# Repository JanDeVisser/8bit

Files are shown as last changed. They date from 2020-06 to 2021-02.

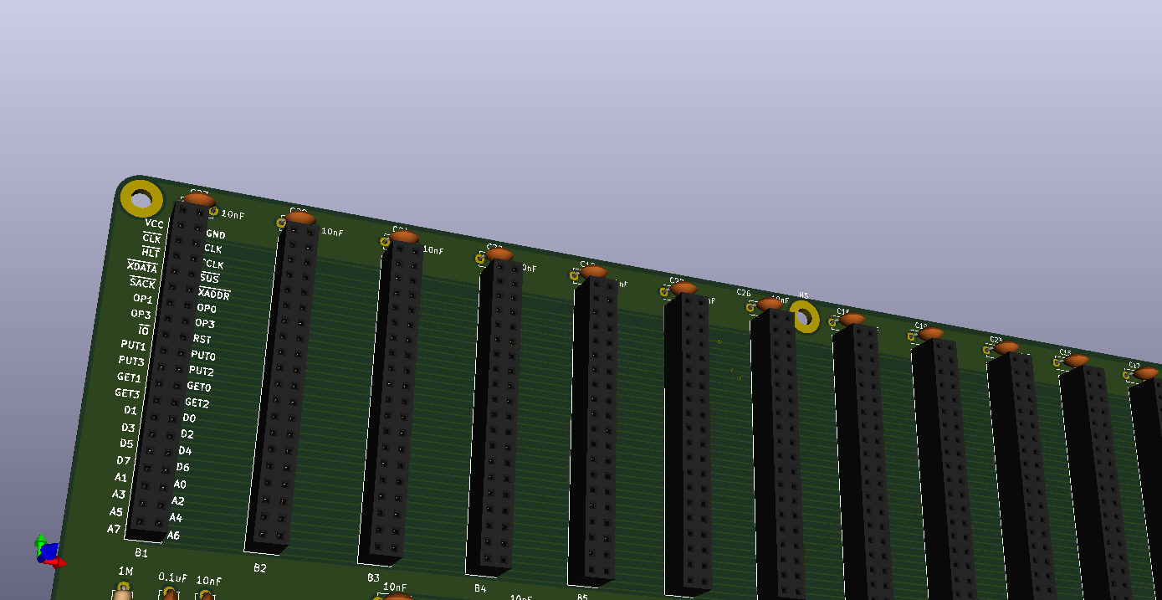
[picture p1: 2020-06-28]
backplane/bus-labels.png

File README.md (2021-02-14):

# A Simple Ben Eater Inspired 8-bit computer

Please describe me.

### Register IDs

ID       | Register       |  R W  | Remarks
---------|----------------|-------|--------------
0000 00  | A              |  x x  |
0001 01  | B              |  x x  |
0010 02  | C              |  x x  |
0011 03  | D              |  x x  |
0100 04  | ALU LHS/Result |  x x  | Put: LHS, Get: Result
0101 05  | ALU Operation  |  - x  | Put: RHS, OP0-3: Operation
0110 06  | Instruction    |  - x  |
0111 07  | Mem            |  x x  |
1000 08  | Prog Counter   |  x x  |
1001 09  | SP             |  x x  |
1010 10  | Si             |  x x  |
1011 11  | Di             |  x x  |
1100 12  | TX             |       |
1101 13  |                |       |
1110 14	 | Monitor        |  x -  |
1111 15  | Mem Addr       |  - x  |

### Control Lines

Pin   | Name                   | Description
------|------------------------|-----------------------
1     | `GND`                  | Common Ground
2     | `VCC`                  | +5V Power
3     | `CLK`                  | Square Wave Clock
4     | ~~`CLK`~~              | Reverse Clock
5     | `^CLK`                 | "Burst" Clock at rising edge of CLK
6     | `HLT`                  | Halts clock
7     | ~~`SUS`~~              | Requests Control Unit to cease dispatching instructions.
8     | ~~`XDATA`~~            | 8 bit Data transfer instruction
9     | ~~`XADDR`~~            | 16 bit address transfer instruction
10    | ~~`SACK`~~             | Set by Control Unit as acknowlegement of SUS.
11-14 | `OP0`-`OP3`            | Custom Operation codes used by various instructions. See below.
15    | `RST`                  | Reset
16    | ~~`IO`~~               | In/Out instruction
17-20 | `PUT0`-`PUT3`          | Register ID of the target of a transfer instruction.
21-24 | `GET0`-`GET3`          | Register ID of the source of a transfer instruction.
25-32 | `D0`-`D7`              | Databus
33-40 | `A0`-`A7` / `A8`-`A15` | Address bus

### Operation Codes

#### XADDR

OP0-3 |Function
---|---
`XX01`|Increment source (Get) register
`XX10`|Decrement source (Get) register

#### XDATA

_When moving data between 8- and 16-bit registers:_

OP0-3 |Function
------|--------
`XXX0`|Transfer to/from the LSB of the 16-bit register
`XXX1`|Transfer to/from the MSB of the 16-bit register

_When the target register is ALU Operation (`0x5`):_

OP0-3|Operation
-----|-----------
`0x0`|`ADD`
`0x1`|`ADC`
`0x2`|`SUB`
`0x3`|`SBB`
...|...
`0x8`|`AND`
`0x9`|`OR`
`0xA`|`XOR`
`0xB`|`NOT LHS`
`0xC`|`SHL`
`0xD`|`SHR`
`0xE`|`CLR`
...|...

## N O T E S

### SBB (Subtract with Borrow)

See here: https://en.wikipedia.org/wiki/Carry_flag#Vs._borrow_flag

We use the convention that when subtracting the processor Carry flag is a borrow flag. This is in line with the Z80 and x68.

### 74xxx253 Function Table

As determined by Julian Ilett in https://www.youtube.com/watch?v=15M63Zqkthk

C3-C0 :arrow_down: BA :arrow_right: | 11 | 10 | 01 | 00 | Operation
------|----|----|----|----|-----------
  0x0  | 0  | 0  | 0  | 0  | All Zero
  0x1  | 0  | 0  | 0  | 1  | A NOR B
  0x2  | 0  | 0  | 1  | 0  | A AND (NOT B)
  0x3  | 0  | 0  | 1  | 1  | NOT B
  0x4  | 0  | 1  | 0  | 0  | (NOT A) AND B
  0x5  | 0  | 1  | 0  | 1  | NOT A
  0x6  | 0  | 1  | 1  | 0  | A XOR B
  0x7  | 0  | 1  | 1  | 1  | A NAND B
  0x8  | 1  | 0  | 0  | 0  | A AND B
  0x9  | 1  | 0  | 0  | 1  | A XNOR B
  0xA  | 1  | 0  | 1  | 0  | A
  0xB  | 1  | 0  | 1  | 1  | A OR (NOT B)
  0xC  | 1  | 1  | 0  | 0  | B
  0xD  | 1  | 1  | 0  | 1  | (NOT A) OR B
  0xE  | 1  | 1  | 1  | 0  | A OR B
  0xF  | 1  | 1  | 1  | 1  | All One

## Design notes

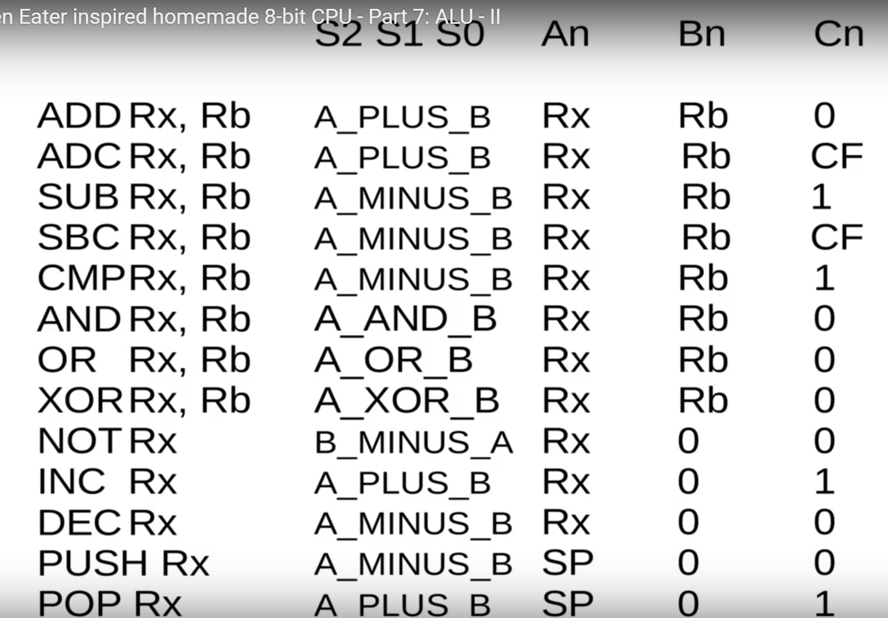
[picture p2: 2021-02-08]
JamesBates_74LS382.png

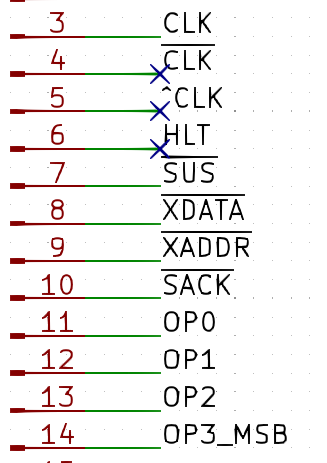
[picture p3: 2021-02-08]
ControlLines.png

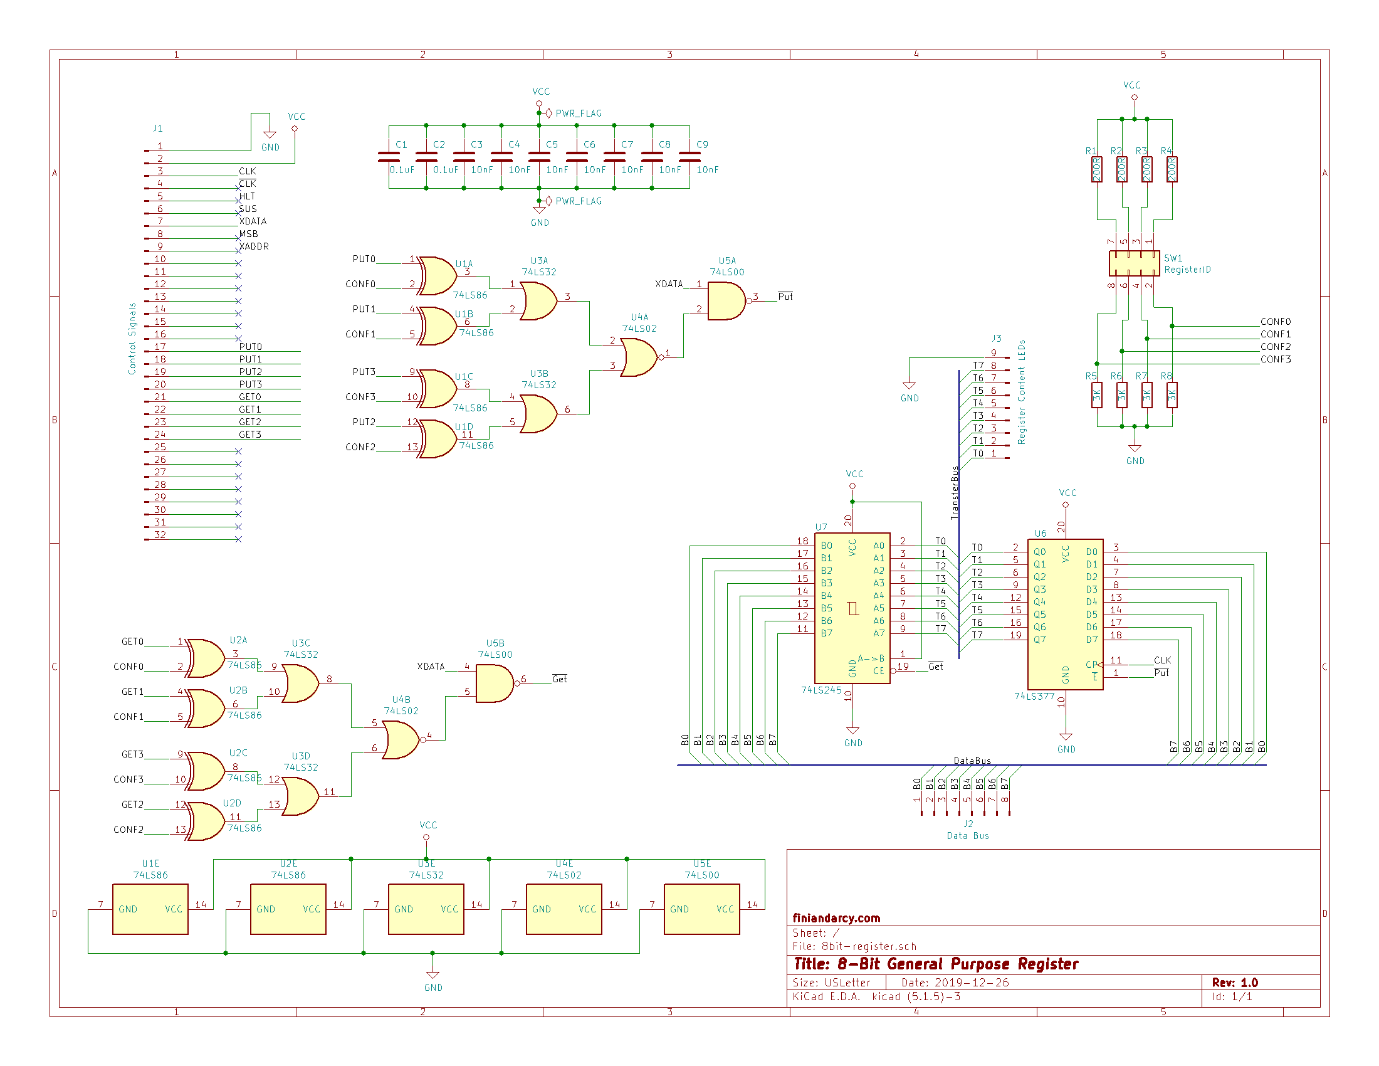
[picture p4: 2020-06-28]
8bit-register/8bit-register.png

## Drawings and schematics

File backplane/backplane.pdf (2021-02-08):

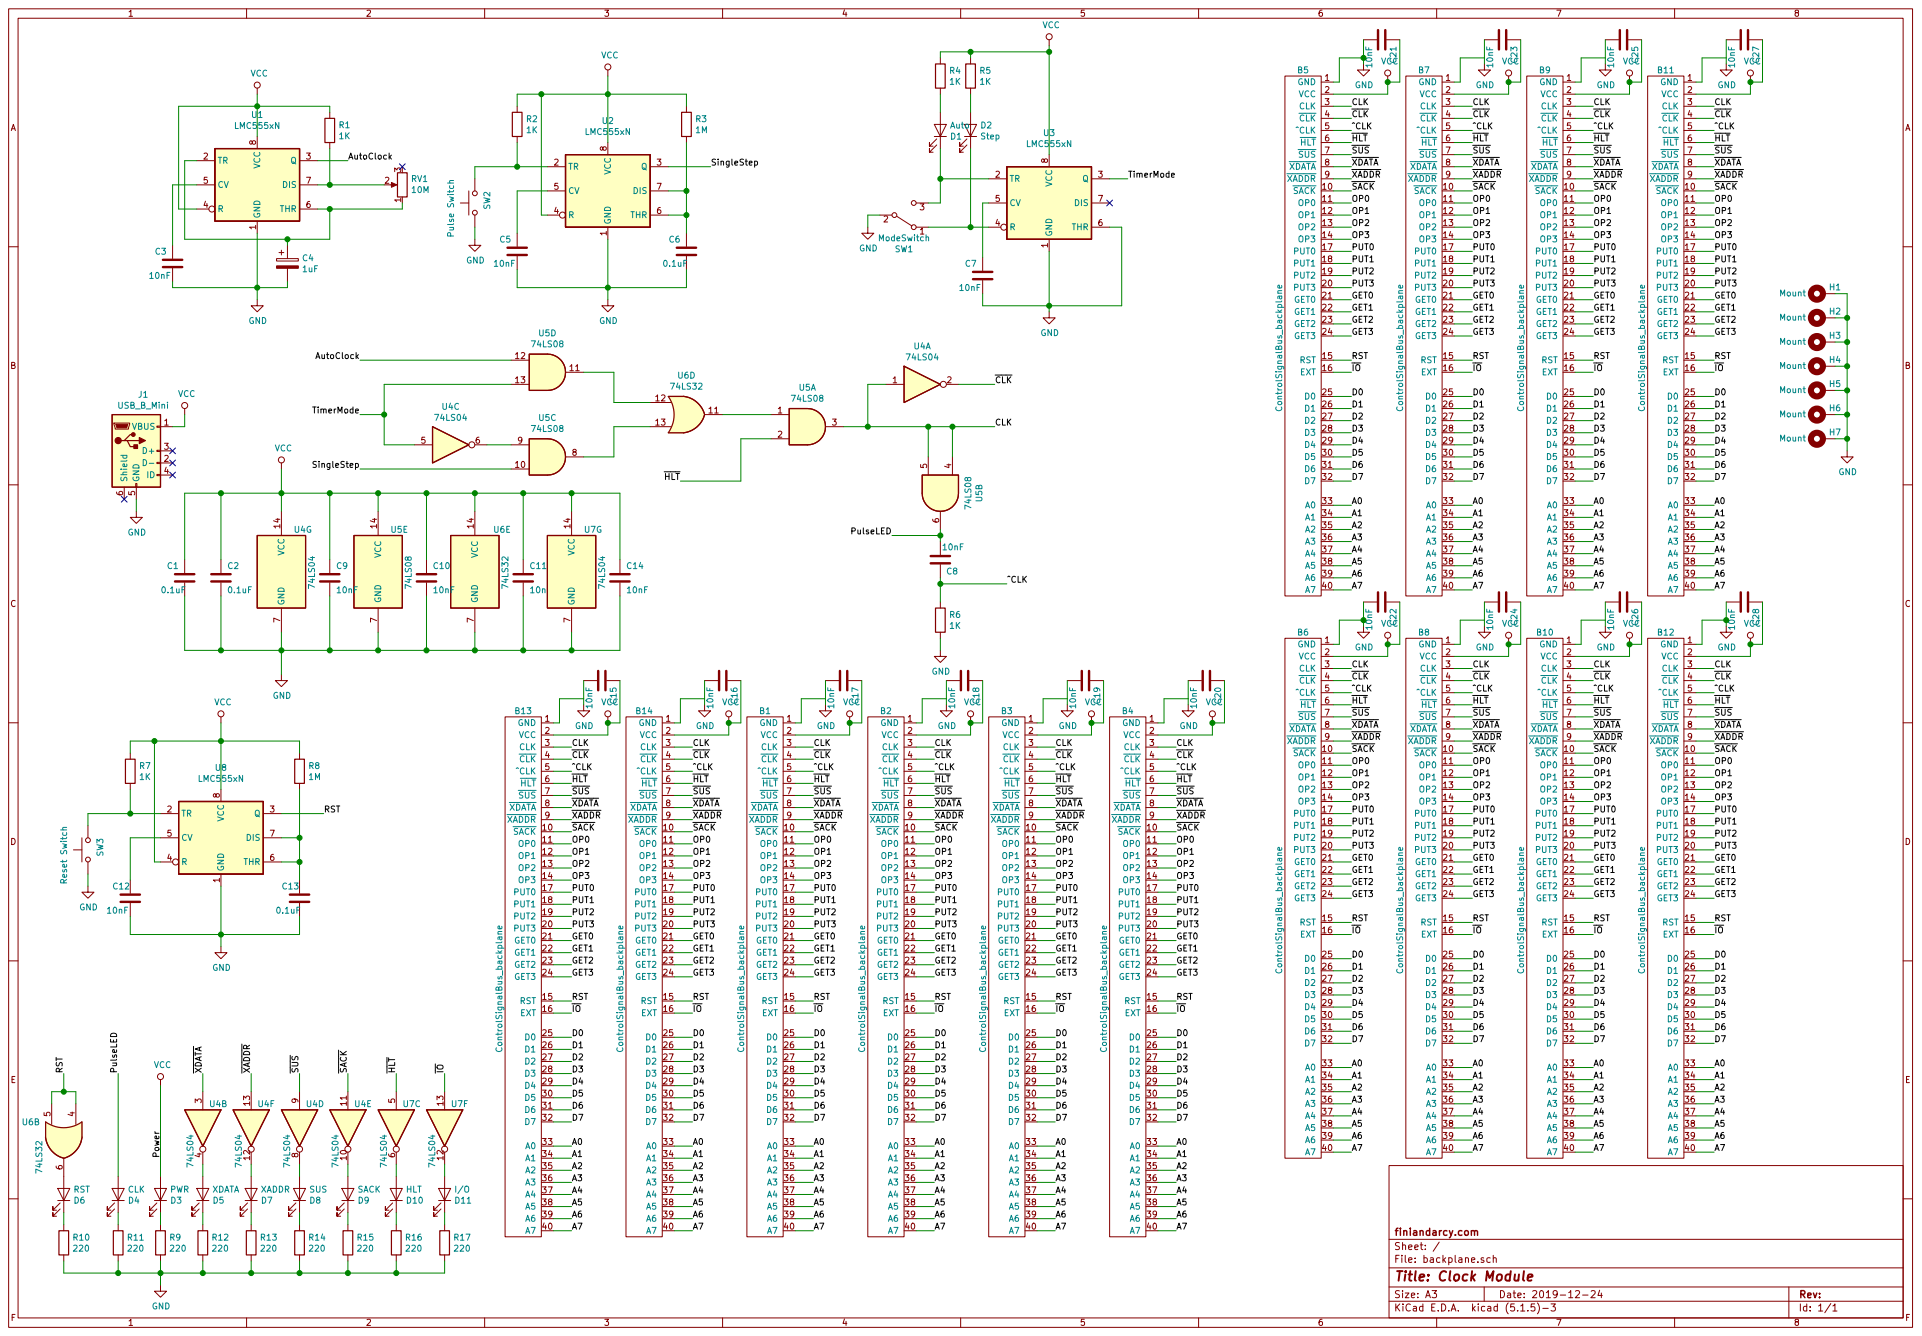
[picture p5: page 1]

^CLK HLT SUS CLK HLT
LMC555xN

VCC GND VCC 14 GND

File: backplane.sch Sheet: / finiandarcy.com

Id: 1/1 Title: Clock Module

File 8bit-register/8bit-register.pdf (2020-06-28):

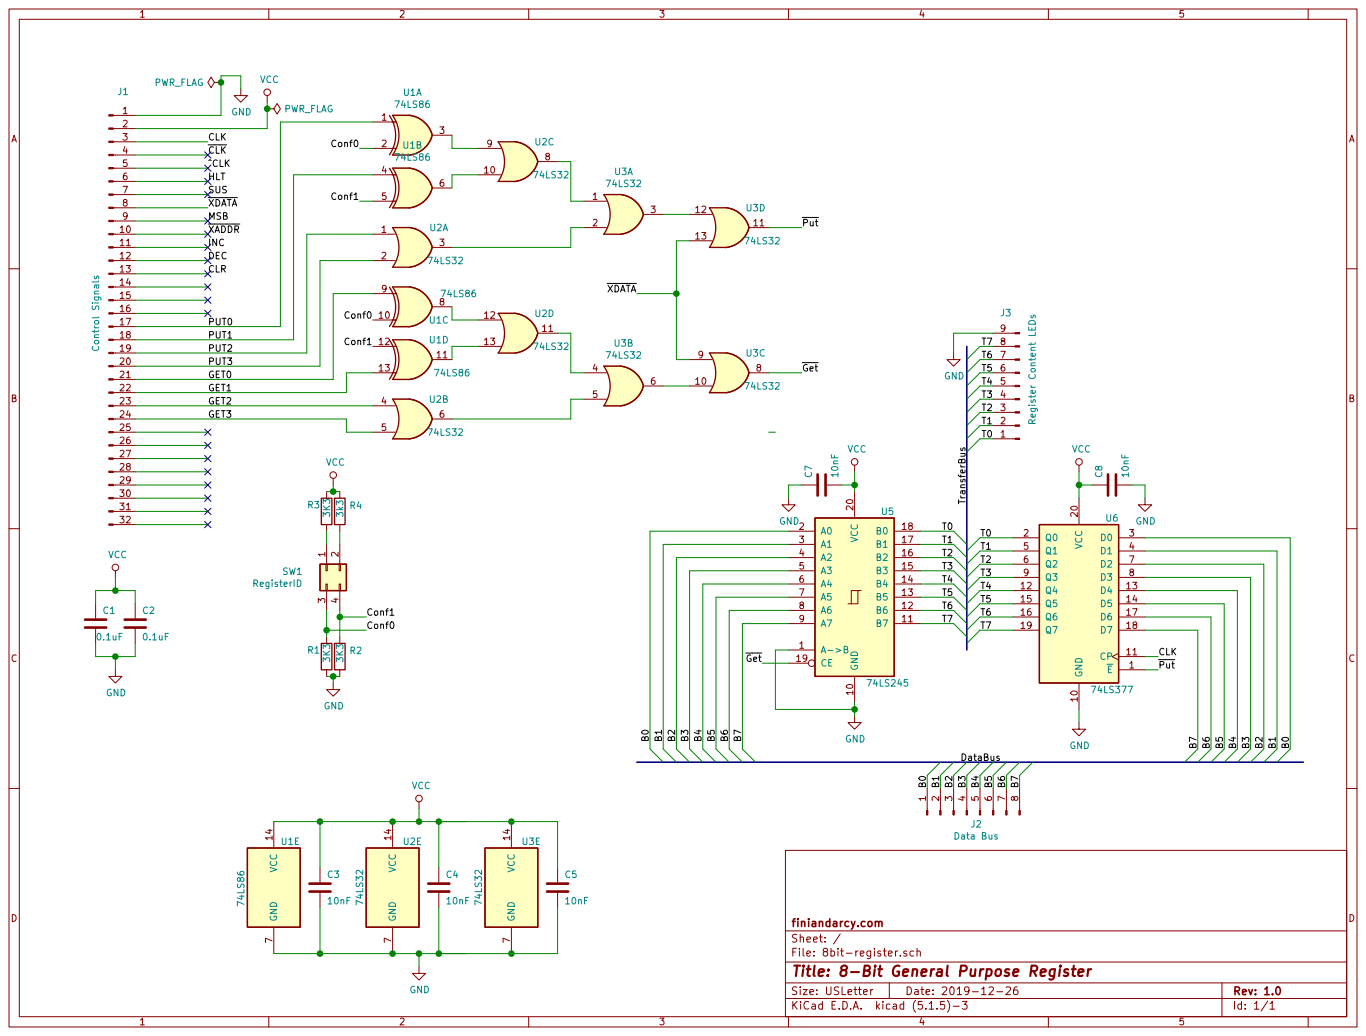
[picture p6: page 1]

File: 8bit-register.sch Sheet: / finiandarcy.com

Id: 1/1 Title: 8-Bit General Purpose Register

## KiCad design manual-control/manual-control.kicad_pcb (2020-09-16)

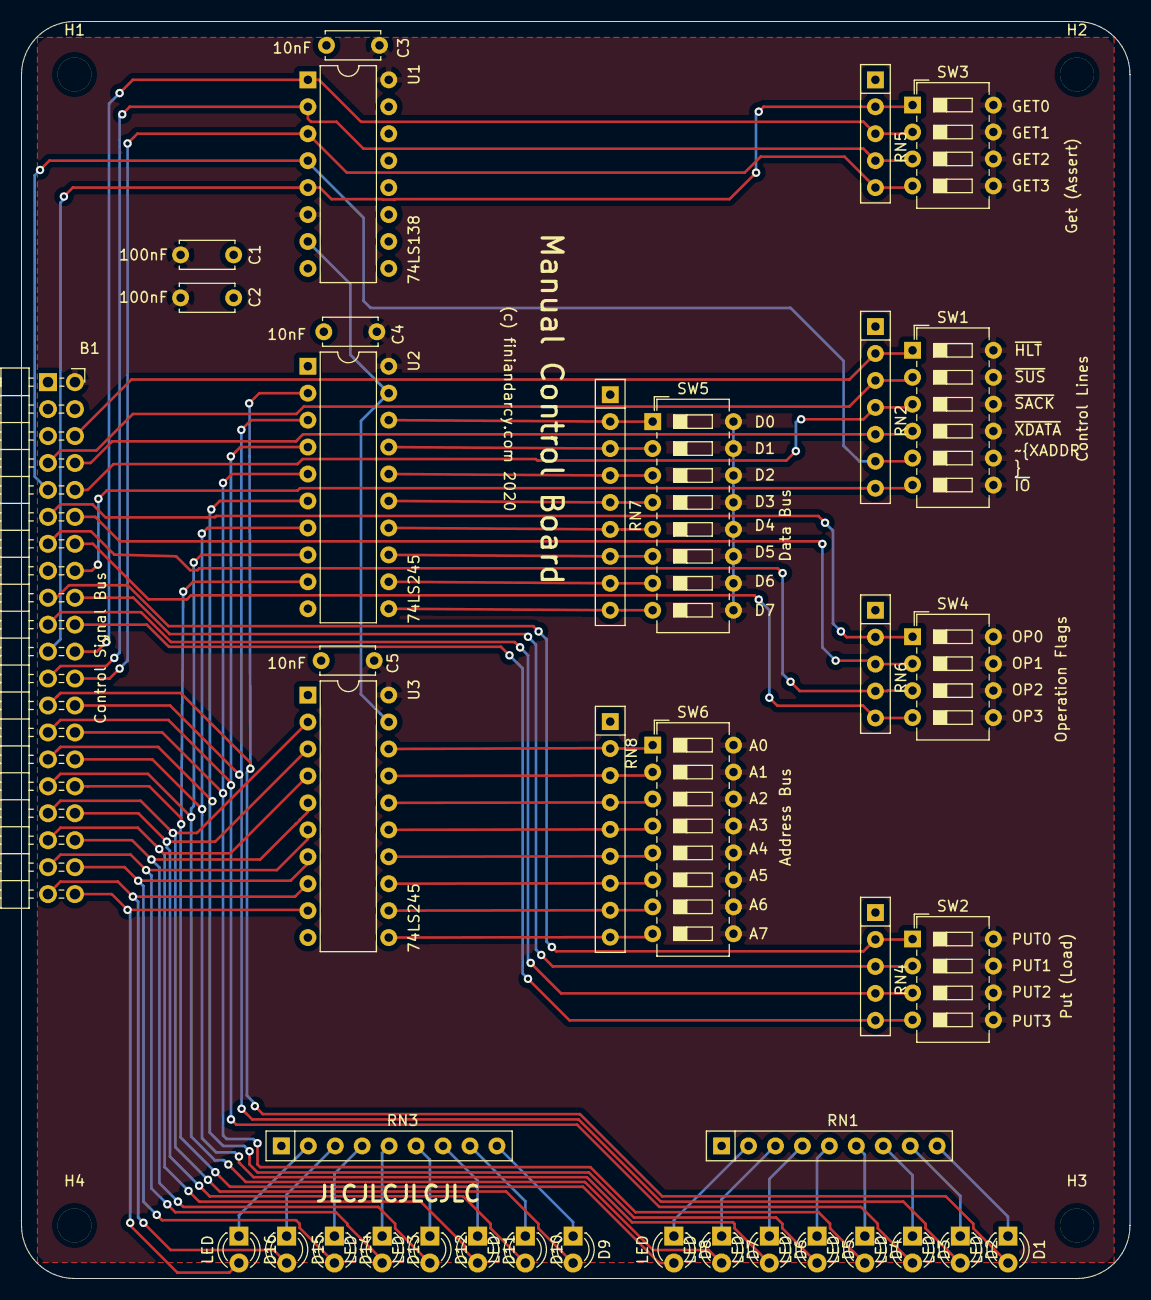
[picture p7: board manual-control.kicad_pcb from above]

Board: 2 copper layers, 104.5 x 118.5 mm, 43 parts (0 on the bottom side), 69 nets.

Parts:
B1: Control Signal Bus; PinHeader_2x20_P2.54mm_Horizontal_Flipped
C1, C2: 100nF; C_Disc_D5.0mm_W2.5mm_P5.00mm
C3, C4, C5: 10nF; C_Disc_D5.0mm_W2.5mm_P5.00mm
D1, D2, D3, D4, D5, D6, D7, D8, D9, D10, D11, D12, D13, D14, D15, D16: LED; LED_D3.0mm
H1, H2, H3, H4: H; MountingHole_3.2mm_M3
RN1, RN3, RN7, RN8: 1K; R_Array_SIP9
RN2: 1K; R_Array_SIP7
RN4, RN5, RN6: 1K; R_Array_SIP5
SW1: Control Lines; SW_DIP_SPSTx06_Slide_6.7x16.8mm_W7.62mm_P2.54mm_LowProfile
SW2: Put (Load); SW_DIP_SPSTx04_Slide_6.7x11.72mm_W7.62mm_P2.54mm_LowProfile
SW3: Get (Assert); SW_DIP_SPSTx04_Slide_6.7x11.72mm_W7.62mm_P2.54mm_LowProfile
SW4: Operation Flags; SW_DIP_SPSTx04_Slide_6.7x11.72mm_W7.62mm_P2.54mm_LowProfile
SW5: Data Bus; SW_DIP_SPSTx08_Slide_6.7x21.88mm_W7.62mm_P2.54mm_LowProfile
SW6: Address Bus; SW_DIP_SPSTx08_Slide_6.7x21.88mm_W7.62mm_P2.54mm_LowProfile
U1: 74LS138; DIP-16_W7.62mm
U2, U3: 74LS245; DIP-20_W7.62mm

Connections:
/A0: B1.33, D9.2, U3.2
/A1: B1.34, D10.2, U3.3
/A2: B1.35, D11.2, U3.4
/A3: B1.36, D12.2, U3.5
/A4: B1.37, D13.2, U3.6
/A5: B1.38, D14.2, U3.7
/A6: B1.39, D15.2, U3.8
/A7: B1.40, D16.2, U3.9
/D0: B1.25, D1.2, U2.2
/D1: B1.26, D2.2, U2.3
/D2: B1.27, D3.2, U2.4
/D3: B1.28, D4.2, U2.5
/D4: B1.29, D5.2, U2.6
/D5: B1.30, D6.2, U2.7
/D6: B1.31, D7.2, U2.8
/D7: B1.32, D8.2, U2.9
/GET0: B1.21, RN5.2, SW3.1, U1.5
/GET1: B1.22, RN5.3, SW3.2, U1.1
/GET2: B1.23, RN5.4, SW3.3, U1.2
/GET3: B1.24, RN5.5, SW3.4, U1.3
/OP0: B1.11, RN6.2, SW4.1
/OP1: B1.12, RN6.3, SW4.2
/OP2: B1.13, RN6.4, SW4.3
/OP3: B1.14, RN6.5, SW4.4
/PUT0: B1.17, RN4.2, SW2.1
/PUT1: B1.18, RN4.3, SW2.2
/PUT2: B1.19, RN4.4, SW2.3
/PUT3: B1.20, RN4.5, SW2.4
/~Get: U1.7, U2.19, U3.19
/~HLT: B1.6, RN2.2, SW1.1
/~IO: B1.16, RN2.7, SW1.6
/~SACK: B1.10, RN2.4, SW1.3
/~SUS: B1.7, RN2.3, SW1.2
/~XADDR: B1.9, RN2.6, SW1.5, U1.4
/~XDATA: B1.8, RN2.5, SW1.4
GND: B1.1, C1.2, C2.2, C3.1, C4.1, C5.1, H1.1, H2.1, H3.1, H4.1, RN1.1, RN2.1, RN3.1, RN4.1, RN5.1, RN6.1, RN7.1, RN8.1, U1.8, U2.1, U2.10, U3.1, U3.10
unnamed: D1.1, RN1.9
unnamed: D2.1, RN1.8
unnamed: D3.1, RN1.7
unnamed: D4.1, RN1.6
unnamed: D5.1, RN1.5
unnamed: D6.1, RN1.4
unnamed: D7.1, RN1.3
unnamed: D8.1, RN1.2
unnamed: D9.1, RN3.9
unnamed: D10.1, RN3.8
unnamed: D11.1, RN3.7
unnamed: D12.1, RN3.6
unnamed: D13.1, RN3.5
unnamed: D14.1, RN3.4
unnamed: D15.1, RN3.3
unnamed: D16.1, RN3.2
unnamed: RN7.2, SW5.1, U2.18
unnamed: RN7.3, SW5.2, U2.17
unnamed: RN7.4, SW5.3, U2.16
unnamed: RN7.5, SW5.4, U2.15
unnamed: RN7.6, SW5.5, U2.14
unnamed: RN7.7, SW5.6, U2.13
unnamed: RN7.8, SW5.7, U2.12
unnamed: RN7.9, SW5.8, U2.11
unnamed: RN8.2, SW6.1, U3.18
unnamed: RN8.3, SW6.2, U3.17
unnamed: RN8.4, SW6.3, U3.16
unnamed: RN8.5, SW6.4, U3.15
unnamed: RN8.6, SW6.5, U3.14
unnamed: RN8.7, SW6.6, U3.13
unnamed: RN8.8, SW6.7, U3.12
unnamed: RN8.9, SW6.8, U3.11
VCC: B1.2, C1.1, C2.1, C3.2, C4.2, C5.2, SW1.7, SW1.8, SW1.9, SW1.10, SW1.11, SW1.12, SW2.5, SW2.6, SW2.7, SW2.8, SW3.5, SW3.6, SW3.7, SW3.8, SW4.5, SW4.6, SW4.7, SW4.8, SW5.9, SW5.10, SW5.11, SW5.12, SW5.13, SW5.14, SW5.15, SW5.16, SW6.9, SW6.10, SW6.11, SW6.12, SW6.13, SW6.14, SW6.15, SW6.16, U1.6, U1.16, U2.20, U3.20

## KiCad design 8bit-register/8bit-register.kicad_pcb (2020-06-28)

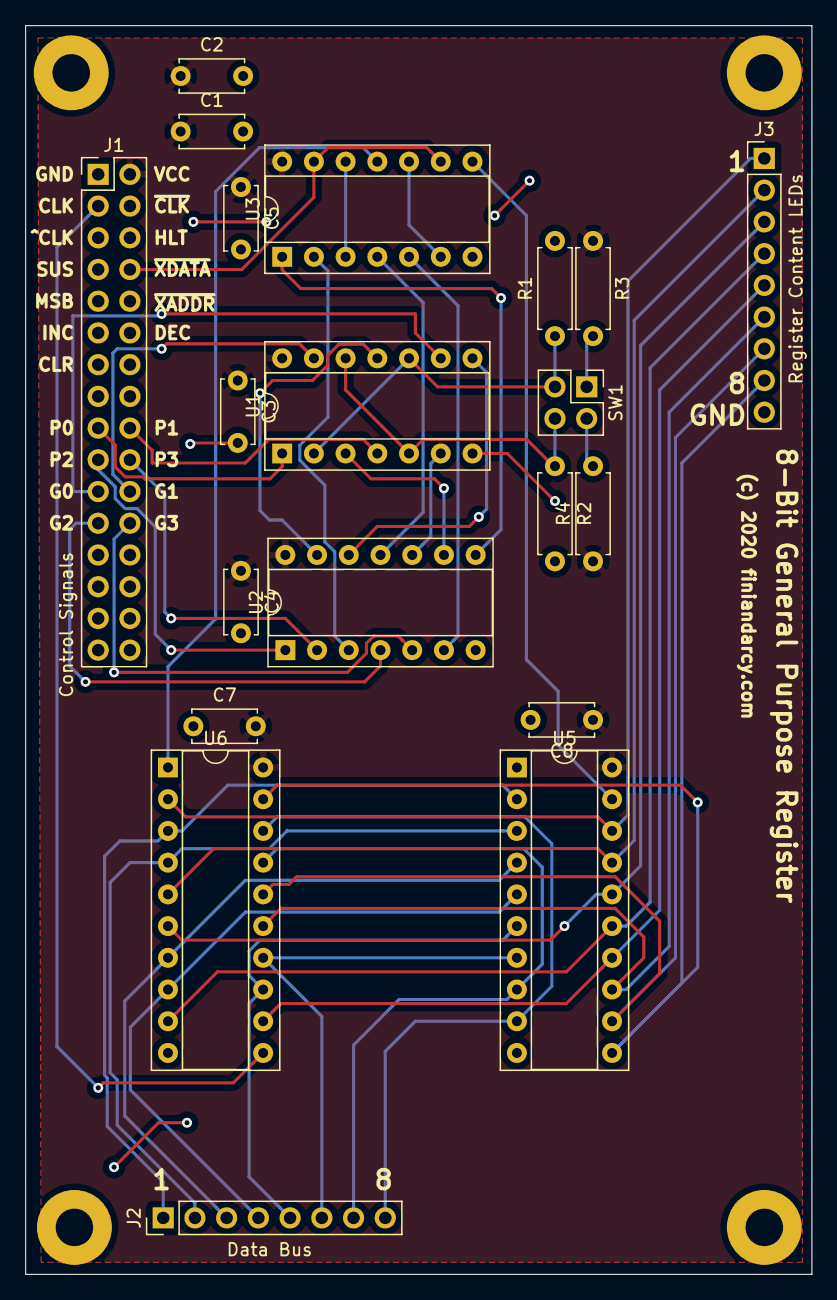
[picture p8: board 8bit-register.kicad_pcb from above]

Board: 2 copper layers, 63.0 x 100.0 mm, 24 parts (0 on the bottom side), 44 nets.

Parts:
C1, C2: 0.1uF; C_Disc_D5.0mm_W2.5mm_P5.00mm
C3, C4, C5, C7, C8: 10nF; C_Disc_D5.0mm_W2.5mm_P5.00mm
J1: Control Signals; PinHeader_2x16_P2.54mm_Vertical
J2: Data Bus; PinHeader_1x08_P2.54mm_Vertical
J3: Register Content LEDs; PinHeader_1x09_P2.54mm_Vertical
M1, M2, M3, M4: MountingHole_3mm_Pad
R1, R2, R3: 3K3; R_Axial_DIN0207_L6.3mm_D2.5mm_P7.62mm_Horizontal
R4: 3k3; R_Axial_DIN0207_L6.3mm_D2.5mm_P7.62mm_Horizontal
SW1: RegisterID; PinHeader_2x02_P2.54mm_Vertical
U1: 74LS86; DIP-14_W7.62mm_Socket
U2, U3: 74LS32; DIP-14_W7.62mm_Socket
U5: 74LS245; DIP-20_W7.62mm_Socket
U6: 74LS377; DIP-20_W7.62mm_Socket

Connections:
/B0: J2.1, U5.2, U6.3
/B1: J2.2, U5.3, U6.4
/B2: J2.3, U5.4, U6.7
/B3: J2.4, U5.5, U6.8
/B4: J2.5, U5.6, U6.13
/B5: J2.6, U5.7, U6.14
/B6: J2.7, U5.8, U6.17
/B7: J2.8, U5.9, U6.18
/CLK: J1.3, U6.11
/Conf0: R1.1, SW1.3, U1.2, U1.10
/Conf1: R2.1, SW1.4, U1.5, U1.12
/GET0: J1.21, U1.9
/GET1: J1.22, U1.13
/GET2: J1.23, U2.4
/GET3: J1.24, U2.5
/PUT0: J1.17, U1.1
/PUT1: J1.18, U1.4
/PUT2: J1.19, U2.1
/PUT3: J1.20, U2.2
/T0: J3.1, U5.18, U6.2
/T1: J3.2, U5.17, U6.5
/T2: J3.3, U5.16, U6.6
/T3: J3.4, U5.15, U6.9
/T4: J3.5, U5.14, U6.12
/T5: J3.6, U5.13, U6.15
/T6: J3.7, U5.12, U6.16
/T7: J3.8, U5.11, U6.19
/~Get: U3.8, U5.19
/~Put: U3.11, U6.1
/~XDATA: J1.8, U3.9, U3.13
GND: C1.2, C2.2, C3.2, C4.2, C5.2, C7.1, C8.2, J1.1, J3.9, R1.2, R2.2, U1.7, U2.7, U3.7, U5.1, U5.10, U6.10
unnamed: R3.2, SW1.1
unnamed: R4.2, SW1.2
unnamed: U1.3, U2.9
unnamed: U1.6, U2.10
unnamed: U1.8, U2.12
unnamed: U1.11, U2.13
unnamed: U2.3, U3.2
unnamed: U2.6, U3.5
unnamed: U2.8, U3.1
unnamed: U2.11, U3.4
unnamed: U3.6, U3.10
unnamed: U3.3, U3.12
VCC: C1.1, C2.1, C3.1, C4.1, C5.1, C7.2, C8.1, J1.2, R3.1, R4.1, U1.14, U2.14, U3.14, U5.20, U6.20

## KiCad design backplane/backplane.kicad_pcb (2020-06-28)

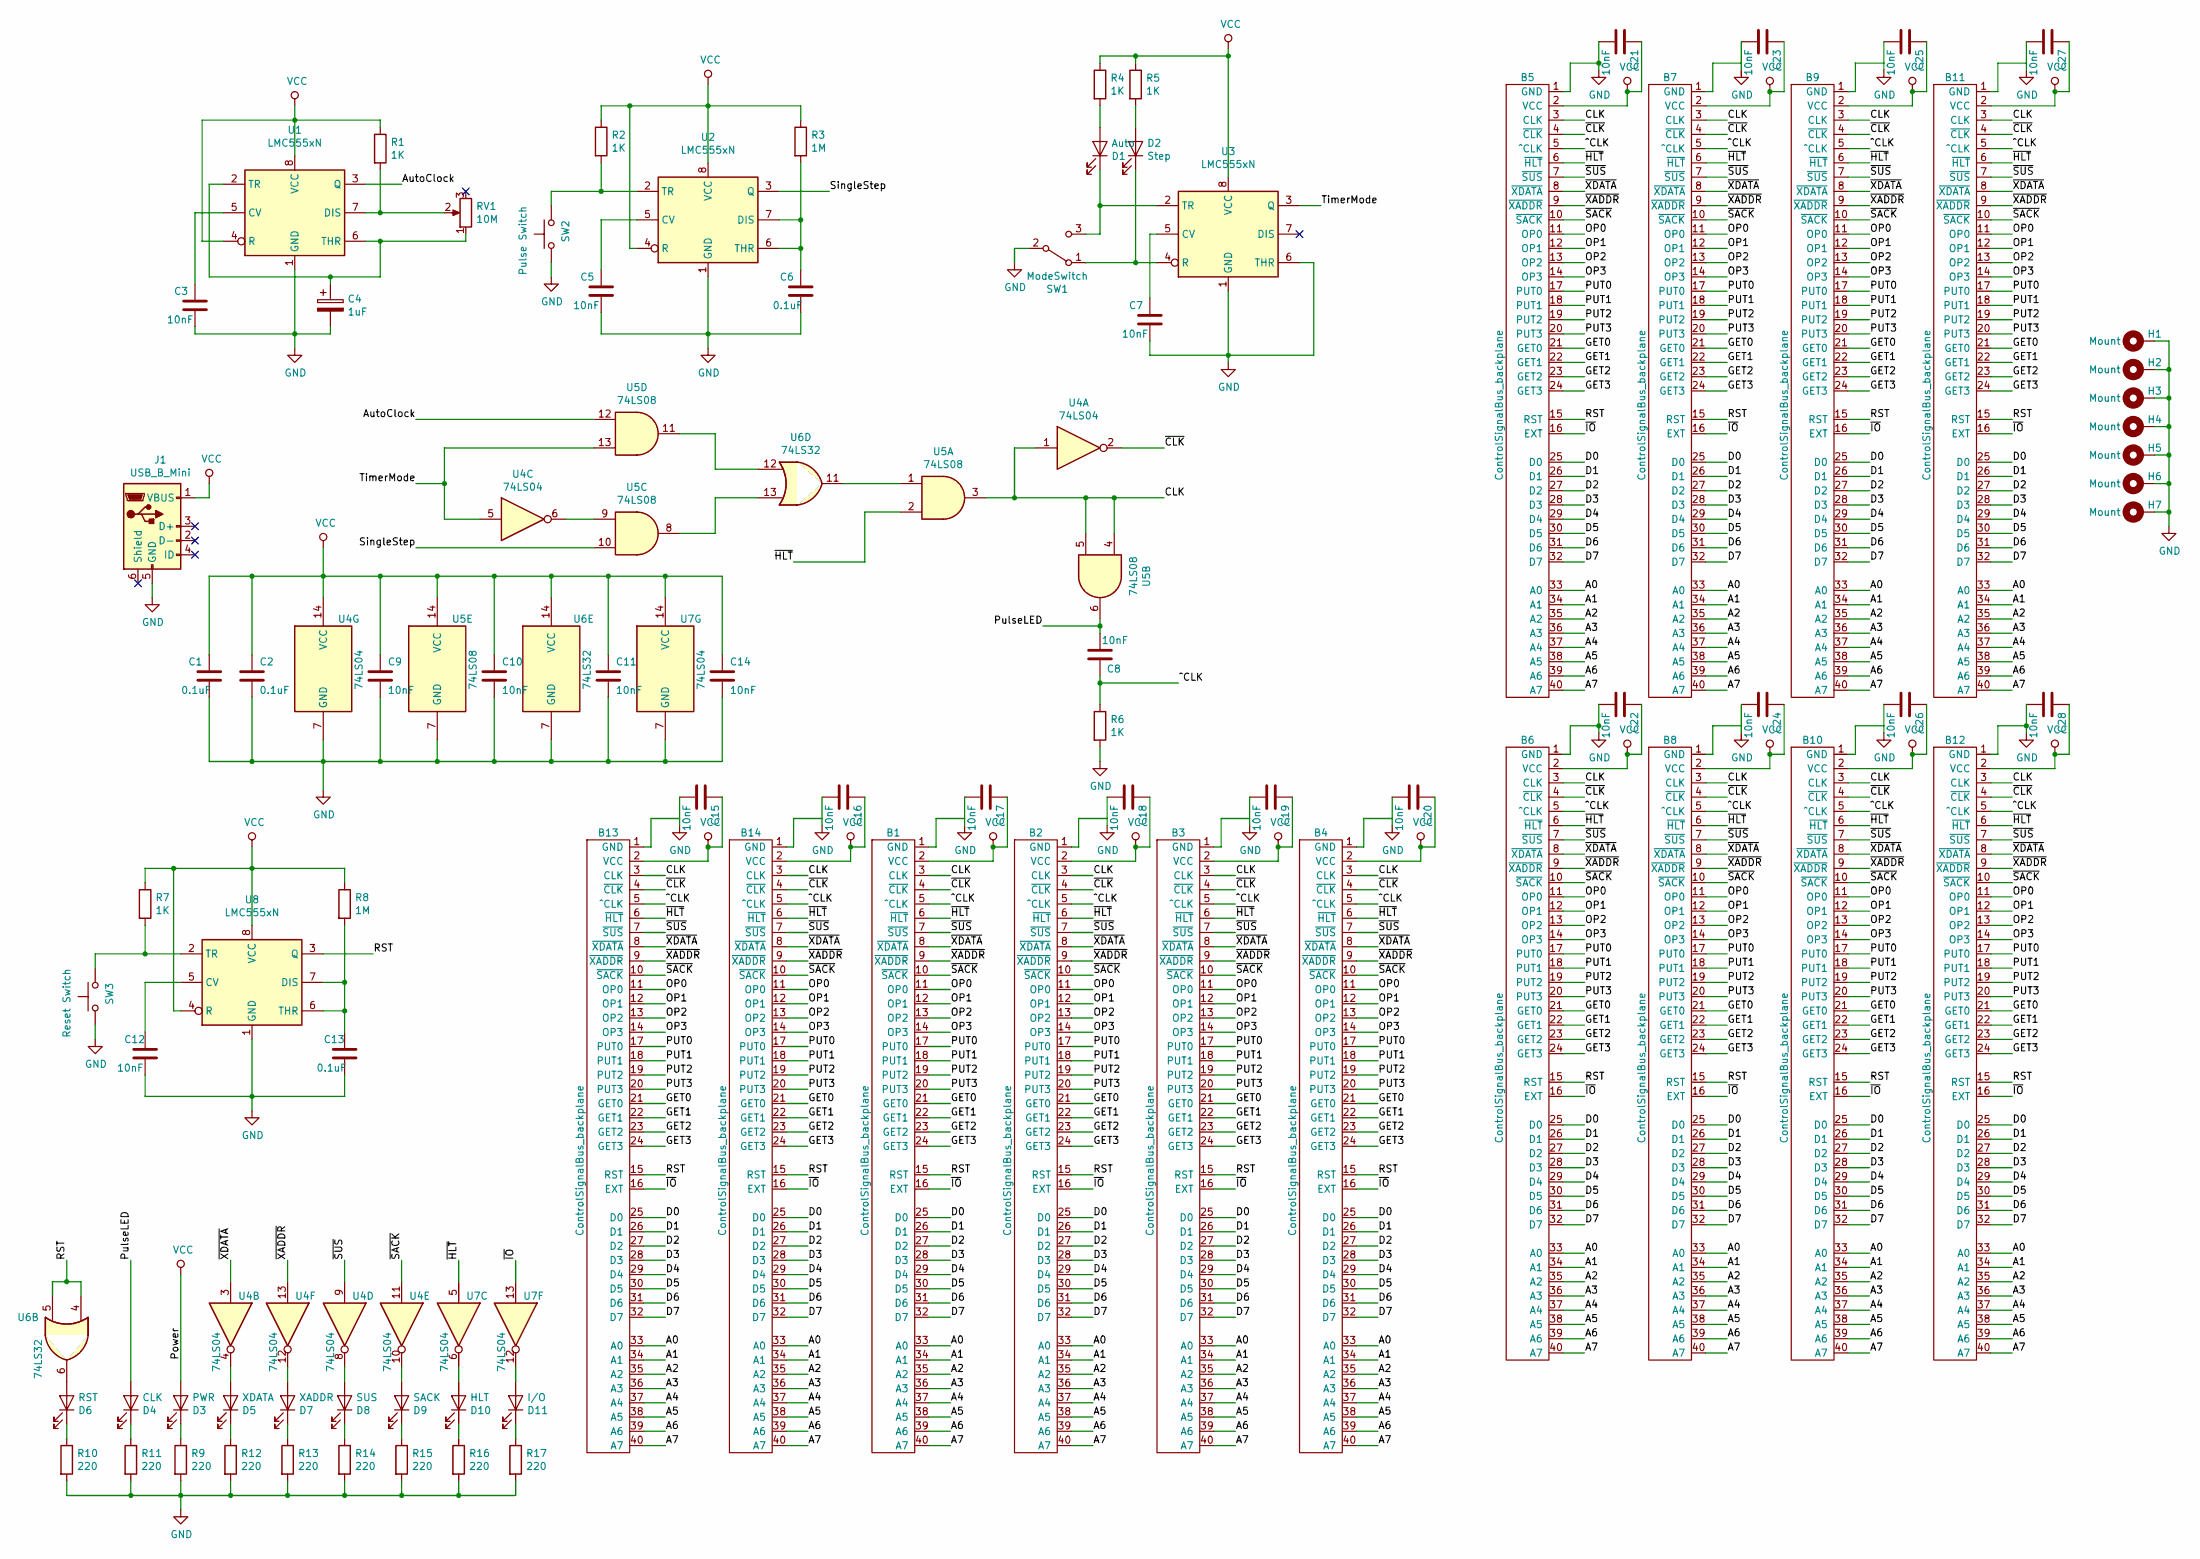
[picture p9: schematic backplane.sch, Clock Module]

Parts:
B1, B2, B3, B4, B5, B6, B7, B8, B9, B10, B11, B12, B13, B14: ControlSignalBus_backplane; PinSocket_2x20_P2.54mm_Vertical
C1, C2, C6, C13: 0.1uF; C_Disc_D5.0mm_W2.5mm_P5.00mm
C3, C5, C7, C8, C9, C10, C11, C12, C14, C15, C16, C17, C18, C19, C20, C21, C22, C23, C24, C25, C26, C27, C28: 10nF; C_Disc_D5.0mm_W2.5mm_P5.00mm
C4: 1uF; C_Radial_D5.0mm_H11.0mm_P2.00mm
D1: Auto; LED_D5.0mm
D2: Step; LED_D5.0mm
D3: PWR; LED_D5.0mm
D4: CLK; LED_D5.0mm
D5: XDATA; LED_D5.0mm
D6: RST; LED_D5.0mm
D7: XADDR; LED_D5.0mm
D8: SUS; LED_D5.0mm
D9: SACK; LED_D5.0mm
D10: HLT; LED_D5.0mm
D11: I/O; LED_D5.0mm
H1, H2, H3, H4, H5, H6, H7: Mount; MountingHole_3.2mm_M3_Pad
J1: USB_B_Mini; TE_2172034-1
R1, R2, R4, R5, R6, R7: 1K; R_Axial_DIN0207_L6.3mm_D2.5mm_P7.62mm_Horizontal
R3, R8: 1M; R_Axial_DIN0207_L6.3mm_D2.5mm_P7.62mm_Horizontal
R9, R10, R11, R12, R13, R14, R15, R16, R17: 220; R_Axial_DIN0207_L6.3mm_D2.5mm_P7.62mm_Horizontal
RV1: 10M; TT-P160KN-0QC15A
SW1: ModeSwitch; 400MSP1R6BLKM6RE
SW2: Pulse Switch; KS11R22CQD
SW3: Reset Switch; KS11R22CQD
U1, U2, U3, U8: LMC555xN; DIP-8_W7.62mm_Socket
U4, U7: 74LS04; DIP-14_W7.62mm_Socket
U5: 74LS08; DIP-14_W7.62mm_Socket
U6: 74LS32; DIP-14_W7.62mm_Socket

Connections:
/A0: B1.33 (A0), B2.33 (A0), B3.33 (A0), B4.33 (A0), B5.33 (A0), B6.33 (A0), B7.33 (A0), B8.33 (A0), B9.33 (A0), B10.33 (A0), B11.33 (A0), B12.33 (A0), B13.33 (A0), B14.33 (A0)
/A1: B1.34 (A1), B2.34 (A1), B3.34 (A1), B4.34 (A1), B5.34 (A1), B6.34 (A1), B7.34 (A1), B8.34 (A1), B9.34 (A1), B10.34 (A1), B11.34 (A1), B12.34 (A1), B13.34 (A1), B14.34 (A1)
/A2: B1.35 (A2), B2.35 (A2), B3.35 (A2), B4.35 (A2), B5.35 (A2), B6.35 (A2), B7.35 (A2), B8.35 (A2), B9.35 (A2), B10.35 (A2), B11.35 (A2), B12.35 (A2), B13.35 (A2), B14.35 (A2)
/A3: B1.36 (A3), B2.36 (A3), B3.36 (A3), B4.36 (A3), B5.36 (A3), B6.36 (A3), B7.36 (A3), B8.36 (A3), B9.36 (A3), B10.36 (A3), B11.36 (A3), B12.36 (A3), B13.36 (A3), B14.36 (A3)
/A4: B1.37 (A4), B2.37 (A4), B3.37 (A4), B4.37 (A4), B5.37 (A4), B6.37 (A4), B7.37 (A4), B8.37 (A4), B9.37 (A4), B10.37 (A4), B11.37 (A4), B12.37 (A4), B13.37 (A4), B14.37 (A4)
/A5: B1.38 (A5), B2.38 (A5), B3.38 (A5), B4.38 (A5), B5.38 (A5), B6.38 (A5), B7.38 (A5), B8.38 (A5), B9.38 (A5), B10.38 (A5), B11.38 (A5), B12.38 (A5), B13.38 (A5), B14.38 (A5)
/A6: B1.39 (A6), B2.39 (A6), B3.39 (A6), B4.39 (A6), B5.39 (A6), B6.39 (A6), B7.39 (A6), B8.39 (A6), B9.39 (A6), B10.39 (A6), B11.39 (A6), B12.39 (A6), B13.39 (A6), B14.39 (A6)
/A7: B1.40 (A7), B2.40 (A7), B3.40 (A7), B4.40 (A7), B5.40 (A7), B6.40 (A7), B7.40 (A7), B8.40 (A7), B9.40 (A7), B10.40 (A7), B11.40 (A7), B12.40 (A7), B13.40 (A7), B14.40 (A7)
/AutoClock: U1.3 (Q), U5.12
/CLK: B1.3 (CLK), B2.3 (CLK), B3.3 (CLK), B4.3 (CLK), B5.3 (CLK), B6.3 (CLK), B7.3 (CLK), B8.3 (CLK), B9.3 (CLK), B10.3 (CLK), B11.3 (CLK), B12.3 (CLK), B13.3 (CLK), B14.3 (CLK), U4.1, U5.3, U5.4, U5.5
/D0: B1.25 (D0), B2.25 (D0), B3.25 (D0), B4.25 (D0), B5.25 (D0), B6.25 (D0), B7.25 (D0), B8.25 (D0), B9.25 (D0), B10.25 (D0), B11.25 (D0), B12.25 (D0), B13.25 (D0), B14.25 (D0)
/D1: B1.26 (D1), B2.26 (D1), B3.26 (D1), B4.26 (D1), B5.26 (D1), B6.26 (D1), B7.26 (D1), B8.26 (D1), B9.26 (D1), B10.26 (D1), B11.26 (D1), B12.26 (D1), B13.26 (D1), B14.26 (D1)
/D2: B1.27 (D2), B2.27 (D2), B3.27 (D2), B4.27 (D2), B5.27 (D2), B6.27 (D2), B7.27 (D2), B8.27 (D2), B9.27 (D2), B10.27 (D2), B11.27 (D2), B12.27 (D2), B13.27 (D2), B14.27 (D2)
/D3: B1.28 (D3), B2.28 (D3), B3.28 (D3), B4.28 (D3), B5.28 (D3), B6.28 (D3), B7.28 (D3), B8.28 (D3), B9.28 (D3), B10.28 (D3), B11.28 (D3), B12.28 (D3), B13.28 (D3), B14.28 (D3)
/D4: B1.29 (D4), B2.29 (D4), B3.29 (D4), B4.29 (D4), B5.29 (D4), B6.29 (D4), B7.29 (D4), B8.29 (D4), B9.29 (D4), B10.29 (D4), B11.29 (D4), B12.29 (D4), B13.29 (D4), B14.29 (D4)
/D5: B1.30 (D5), B2.30 (D5), B3.30 (D5), B4.30 (D5), B5.30 (D5), B6.30 (D5), B7.30 (D5), B8.30 (D5), B9.30 (D5), B10.30 (D5), B11.30 (D5), B12.30 (D5), B13.30 (D5), B14.30 (D5)
/D6: B1.31 (D6), B2.31 (D6), B3.31 (D6), B4.31 (D6), B5.31 (D6), B6.31 (D6), B7.31 (D6), B8.31 (D6), B9.31 (D6), B10.31 (D6), B11.31 (D6), B12.31 (D6), B13.31 (D6), B14.31 (D6)
/D7: B1.32 (D7), B2.32 (D7), B3.32 (D7), B4.32 (D7), B5.32 (D7), B6.32 (D7), B7.32 (D7), B8.32 (D7), B9.32 (D7), B10.32 (D7), B11.32 (D7), B12.32 (D7), B13.32 (D7), B14.32 (D7)
/GET0: B1.21 (GET0), B2.21 (GET0), B3.21 (GET0), B4.21 (GET0), B5.21 (GET0), B6.21 (GET0), B7.21 (GET0), B8.21 (GET0), B9.21 (GET0), B10.21 (GET0), B11.21 (GET0), B12.21 (GET0), B13.21 (GET0), B14.21 (GET0)
/GET1: B1.22 (GET1), B2.22 (GET1), B3.22 (GET1), B4.22 (GET1), B5.22 (GET1), B6.22 (GET1), B7.22 (GET1), B8.22 (GET1), B9.22 (GET1), B10.22 (GET1), B11.22 (GET1), B12.22 (GET1), B13.22 (GET1), B14.22 (GET1)
/GET2: B1.23 (GET2), B2.23 (GET2), B3.23 (GET2), B4.23 (GET2), B5.23 (GET2), B6.23 (GET2), B7.23 (GET2), B8.23 (GET2), B9.23 (GET2), B10.23 (GET2), B11.23 (GET2), B12.23 (GET2), B13.23 (GET2), B14.23 (GET2)
/GET3: B1.24 (GET3), B2.24 (GET3), B3.24 (GET3), B4.24 (GET3), B5.24 (GET3), B6.24 (GET3), B7.24 (GET3), B8.24 (GET3), B9.24 (GET3), B10.24 (GET3), B11.24 (GET3), B12.24 (GET3), B13.24 (GET3), B14.24 (GET3)
/OP0: B1.11 (OP0), B2.11 (OP0), B3.11 (OP0), B4.11 (OP0), B5.11 (OP0), B6.11 (OP0), B7.11 (OP0), B8.11 (OP0), B9.11 (OP0), B10.11 (OP0), B11.11 (OP0), B12.11 (OP0), B13.11 (OP0), B14.11 (OP0)
/OP1: B1.12 (OP1), B2.12 (OP1), B3.12 (OP1), B4.12 (OP1), B5.12 (OP1), B6.12 (OP1), B7.12 (OP1), B8.12 (OP1), B9.12 (OP1), B10.12 (OP1), B11.12 (OP1), B12.12 (OP1), B13.12 (OP1), B14.12 (OP1)
/OP2: B1.13 (OP2), B2.13 (OP2), B3.13 (OP2), B4.13 (OP2), B5.13 (OP2), B6.13 (OP2), B7.13 (OP2), B8.13 (OP2), B9.13 (OP2), B10.13 (OP2), B11.13 (OP2), B12.13 (OP2), B13.13 (OP2), B14.13 (OP2)
/OP3: B1.14 (OP3), B2.14 (OP3), B3.14 (OP3), B4.14 (OP3), B5.14 (OP3), B6.14 (OP3), B7.14 (OP3), B8.14 (OP3), B9.14 (OP3), B10.14 (OP3), B11.14 (OP3), B12.14 (OP3), B13.14 (OP3), B14.14 (OP3)
/PUT0: B1.17 (PUT0), B2.17 (PUT0), B3.17 (PUT0), B4.17 (PUT0), B5.17 (PUT0), B6.17 (PUT0), B7.17 (PUT0), B8.17 (PUT0), B9.17 (PUT0), B10.17 (PUT0), B11.17 (PUT0), B12.17 (PUT0), B13.17 (PUT0), B14.17 (PUT0)
/PUT1: B1.18 (PUT1), B2.18 (PUT1), B3.18 (PUT1), B4.18 (PUT1), B5.18 (PUT1), B6.18 (PUT1), B7.18 (PUT1), B8.18 (PUT1), B9.18 (PUT1), B10.18 (PUT1), B11.18 (PUT1), B12.18 (PUT1), B13.18 (PUT1), B14.18 (PUT1)
/PUT2: B1.19 (PUT2), B2.19 (PUT2), B3.19 (PUT2), B4.19 (PUT2), B5.19 (PUT2), B6.19 (PUT2), B7.19 (PUT2), B8.19 (PUT2), B9.19 (PUT2), B10.19 (PUT2), B11.19 (PUT2), B12.19 (PUT2), B13.19 (PUT2), B14.19 (PUT2)
/PUT3: B1.20 (PUT3), B2.20 (PUT3), B3.20 (PUT3), B4.20 (PUT3), B5.20 (PUT3), B6.20 (PUT3), B7.20 (PUT3), B8.20 (PUT3), B9.20 (PUT3), B10.20 (PUT3), B11.20 (PUT3), B12.20 (PUT3), B13.20 (PUT3), B14.20 (PUT3)
/PulseLED: C8.2, D4.2 (A), U5.6
/RST: B1.15 (RST), B2.15 (RST), B3.15 (RST), B4.15 (RST), B5.15 (RST), B6.15 (RST), B7.15 (RST), B8.15 (RST), B9.15 (RST), B10.15 (RST), B11.15 (RST), B12.15 (RST), B13.15 (RST), B14.15 (RST), U6.4, U6.5, U8.3 (Q)
/SingleStep: U2.3 (Q), U5.10
/TimerMode: U3.3 (Q), U4.5, U5.13
/^CLK: B1.5 (^CLK), B2.5 (^CLK), B3.5 (^CLK), B4.5 (^CLK), B5.5 (^CLK), B6.5 (^CLK), B7.5 (^CLK), B8.5 (^CLK), B9.5 (^CLK), B10.5 (^CLK), B11.5 (^CLK), B12.5 (^CLK), B13.5 (^CLK), B14.5 (^CLK), C8.1, R6.1
/~CLK: B1.4 (~CLK), B2.4 (~CLK), B3.4 (~CLK), B4.4 (~CLK), B5.4 (~CLK), B6.4 (~CLK), B7.4 (~CLK), B8.4 (~CLK), B9.4 (~CLK), B10.4 (~CLK), B11.4 (~CLK), B12.4 (~CLK), B13.4 (~CLK), B14.4 (~CLK), U4.2
/~HLT: B1.6 (~HLT), B2.6 (~HLT), B3.6 (~HLT), B4.6 (~HLT), B5.6 (~HLT), B6.6 (~HLT), B7.6 (~HLT), B8.6 (~HLT), B9.6 (~HLT), B10.6 (~HLT), B11.6 (~HLT), B12.6 (~HLT), B13.6 (~HLT), B14.6 (~HLT), U5.2, U7.5
/~IO: B1.16 (EXT), B2.16 (EXT), B3.16 (EXT), B4.16 (EXT), B5.16 (EXT), B6.16 (EXT), B7.16 (EXT), B8.16 (EXT), B9.16 (EXT), B10.16 (EXT), B11.16 (EXT), B12.16 (EXT), B13.16 (EXT), B14.16 (EXT), U7.13
/~SACK: B1.10 (~SACK), B2.10 (~SACK), B3.10 (~SACK), B4.10 (~SACK), B5.10 (~SACK), B6.10 (~SACK), B7.10 (~SACK), B8.10 (~SACK), B9.10 (~SACK), B10.10 (~SACK), B11.10 (~SACK), B12.10 (~SACK), B13.10 (~SACK), B14.10 (~SACK), U4.11
/~SUS: B1.7 (~SUS), B2.7 (~SUS), B3.7 (~SUS), B4.7 (~SUS), B5.7 (~SUS), B6.7 (~SUS), B7.7 (~SUS), B8.7 (~SUS), B9.7 (~SUS), B10.7 (~SUS), B11.7 (~SUS), B12.7 (~SUS), B13.7 (~SUS), B14.7 (~SUS), U4.9
/~XADDR: B1.9 (~XADDR), B2.9 (~XADDR), B3.9 (~XADDR), B4.9 (~XADDR), B5.9 (~XADDR), B6.9 (~XADDR), B7.9 (~XADDR), B8.9 (~XADDR), B9.9 (~XADDR), B10.9 (~XADDR), B11.9 (~XADDR), B12.9 (~XADDR), B13.9 (~XADDR), B14.9 (~XADDR), U4.13
/~XDATA: B1.8 (~XDATA), B2.8 (~XDATA), B3.8 (~XDATA), B4.8 (~XDATA), B5.8 (~XDATA), B6.8 (~XDATA), B7.8 (~XDATA), B8.8 (~XDATA), B9.8 (~XDATA), B10.8 (~XDATA), B11.8 (~XDATA), B12.8 (~XDATA), B13.8 (~XDATA), B14.8 (~XDATA), U4.3
GND: B1.1 (GND), B2.1 (GND), B3.1 (GND), B4.1 (GND), B5.1 (GND), B6.1 (GND), B7.1 (GND), B8.1 (GND), B9.1 (GND), B10.1 (GND), B11.1 (GND), B12.1 (GND), B13.1 (GND), B14.1 (GND), C1.2, C2.2, C3.2, C4.2, C5.2, C6.2, C7.2, C9.2, C10.2, C11.2, C12.2, C13.2, C14.2, C15.2, C16.2, C17.2, C18.2, C19.2, C20.2, C21.2, C22.2, C23.2, C24.2, C25.2, C26.2, C27.2, C28.2, H1.1, H2.1, H3.1, H4.1, H5.1, H6.1, H7.1, J1.5 (GND), R6.2, R9.2, R10.2, R11.2, R12.2, R13.2, R14.2, R15.2, R16.2, R17.2, SW1.2 (B), SW2.1, SW3.1, U1.1 (GND), U2.1 (GND), U3.1 (GND), U3.6 (THR), U4.7 (GND), U5.7 (GND), U6.7 (GND), U7.7 (GND), U8.1 (GND)
unnamed: C3.1, U1.5 (CV)
unnamed: C4.1, RV1.1, U1.2 (TR), U1.6 (THR)
unnamed: C5.1, U2.5 (CV)
unnamed: C6.1, R3.2, U2.6 (THR), U2.7 (DIS)
unnamed: C7.1, U3.5 (CV)
unnamed: C12.1, U8.5 (CV)
unnamed: C13.1, R8.2, U8.6 (THR), U8.7 (DIS)
unnamed: D1.1 (K), SW1.3 (C), U3.2 (TR)
unnamed: D1.2 (A), R4.2
unnamed: D2.1 (K), SW1.1 (A), U3.4 (R)
unnamed: D2.2 (A), R5.2
unnamed: D3.1 (K), R9.1
unnamed: D4.1 (K), R11.1
unnamed: D5.1 (K), R12.1
unnamed: D5.2 (A), U4.4
unnamed: D6.1 (K), R10.1
unnamed: D6.2 (A), U6.6
unnamed: D7.1 (K), R13.1
unnamed: D7.2 (A), U4.12
unnamed: D8.1 (K), R14.1
unnamed: D8.2 (A), U4.8
unnamed: D9.1 (K), R15.1
unnamed: D9.2 (A), U4.10
unnamed: D10.1 (K), R16.1
unnamed: D10.2 (A), U7.6
unnamed: D11.1 (K), R17.1
unnamed: D11.2 (A), U7.12
unnamed: R1.2, RV1.2, U1.7 (DIS)
unnamed: R2.2, SW2.2, U2.2 (TR)
unnamed: R7.2, SW3.2, U8.2 (TR)
unnamed: U4.6, U5.9
unnamed: U5.1, U6.11
unnamed: U5.8, U6.13
unnamed: U5.11, U6.12
VCC: B1.2 (VCC), B2.2 (VCC), B3.2 (VCC), B4.2 (VCC), B5.2 (VCC), B6.2 (VCC), B7.2 (VCC), B8.2 (VCC), B9.2 (VCC), B10.2 (VCC), B11.2 (VCC), B12.2 (VCC), B13.2 (VCC), B14.2 (VCC), C1.1, C2.1, C9.1, C10.1, C11.1, C14.1, C15.1, C16.1, C17.1, C18.1, C19.1, C20.1, C21.1, C22.1, C23.1, C24.1, C25.1, C26.1, C27.1, C28.1, D3.2 (A), J1.1 (VBUS), R1.1, R2.1, R3.1, R4.1, R5.1, R7.1, R8.1, U1.4 (R), U1.8 (VCC), U2.4 (R), U2.8 (VCC), U3.8 (VCC), U4.14 (VCC), U5.14 (VCC), U6.14 (VCC), U7.14 (VCC), U8.4 (R), U8.8 (VCC)

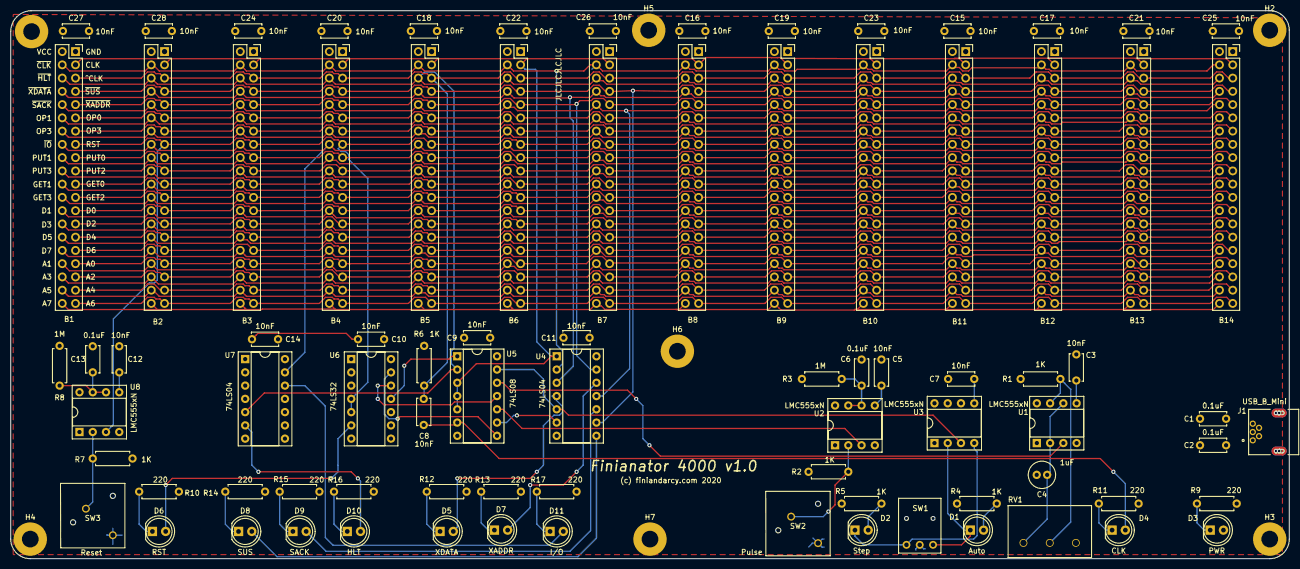
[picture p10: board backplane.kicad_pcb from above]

Board: 2 copper layers, 245.0 x 105.0 mm, 90 parts (0 on the bottom side), 78 nets.

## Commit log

2020-09-16 version 1
    [manual-control.kicad_pcb, manual-control.sch]
2021-02-08 mov (xxxx), gp and mov (di), gp tested
2021-02-08 mov (xxxx), si|di|cd and mov (si|di), cd tested
2021-02-22 Assembler first cut
2021-03-01 Interrupts: set NMI vector, RTI, trigger interrupt service.
2021-03-01 Interrupt was only set when debug was true

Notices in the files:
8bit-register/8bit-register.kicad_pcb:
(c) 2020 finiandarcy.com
